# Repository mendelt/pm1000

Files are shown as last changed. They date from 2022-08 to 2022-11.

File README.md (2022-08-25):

# Documentation for racking up Yamaha PM1000 channel strips

Requirements;
- Two channel strips in one 2U 19inch rack enclosure
- Internal power supply that provides 44V to two strips
  - We're assuming 100mA nominal power draw per channel strip 200mA peak (for now)
  - 44V (or 48V if possible) switchable phantom power
  - Uses 1x 44V or 2x 22V transformer (VA rating tbd)
- Phantom power is supplied via two 6k8 resistors and not via the center tap of the input transformer
- We're using the original Tamura input and output transformers where possible.
- Power switch on the front panel
- Power led on the front panel
- Phantom power switchable per channel
- Phantom power led per channel
- TS unbalanced instrument input

This project will include
- Instructions on how to prepare the channel strips
- PSU PCB design
- Front panel designs

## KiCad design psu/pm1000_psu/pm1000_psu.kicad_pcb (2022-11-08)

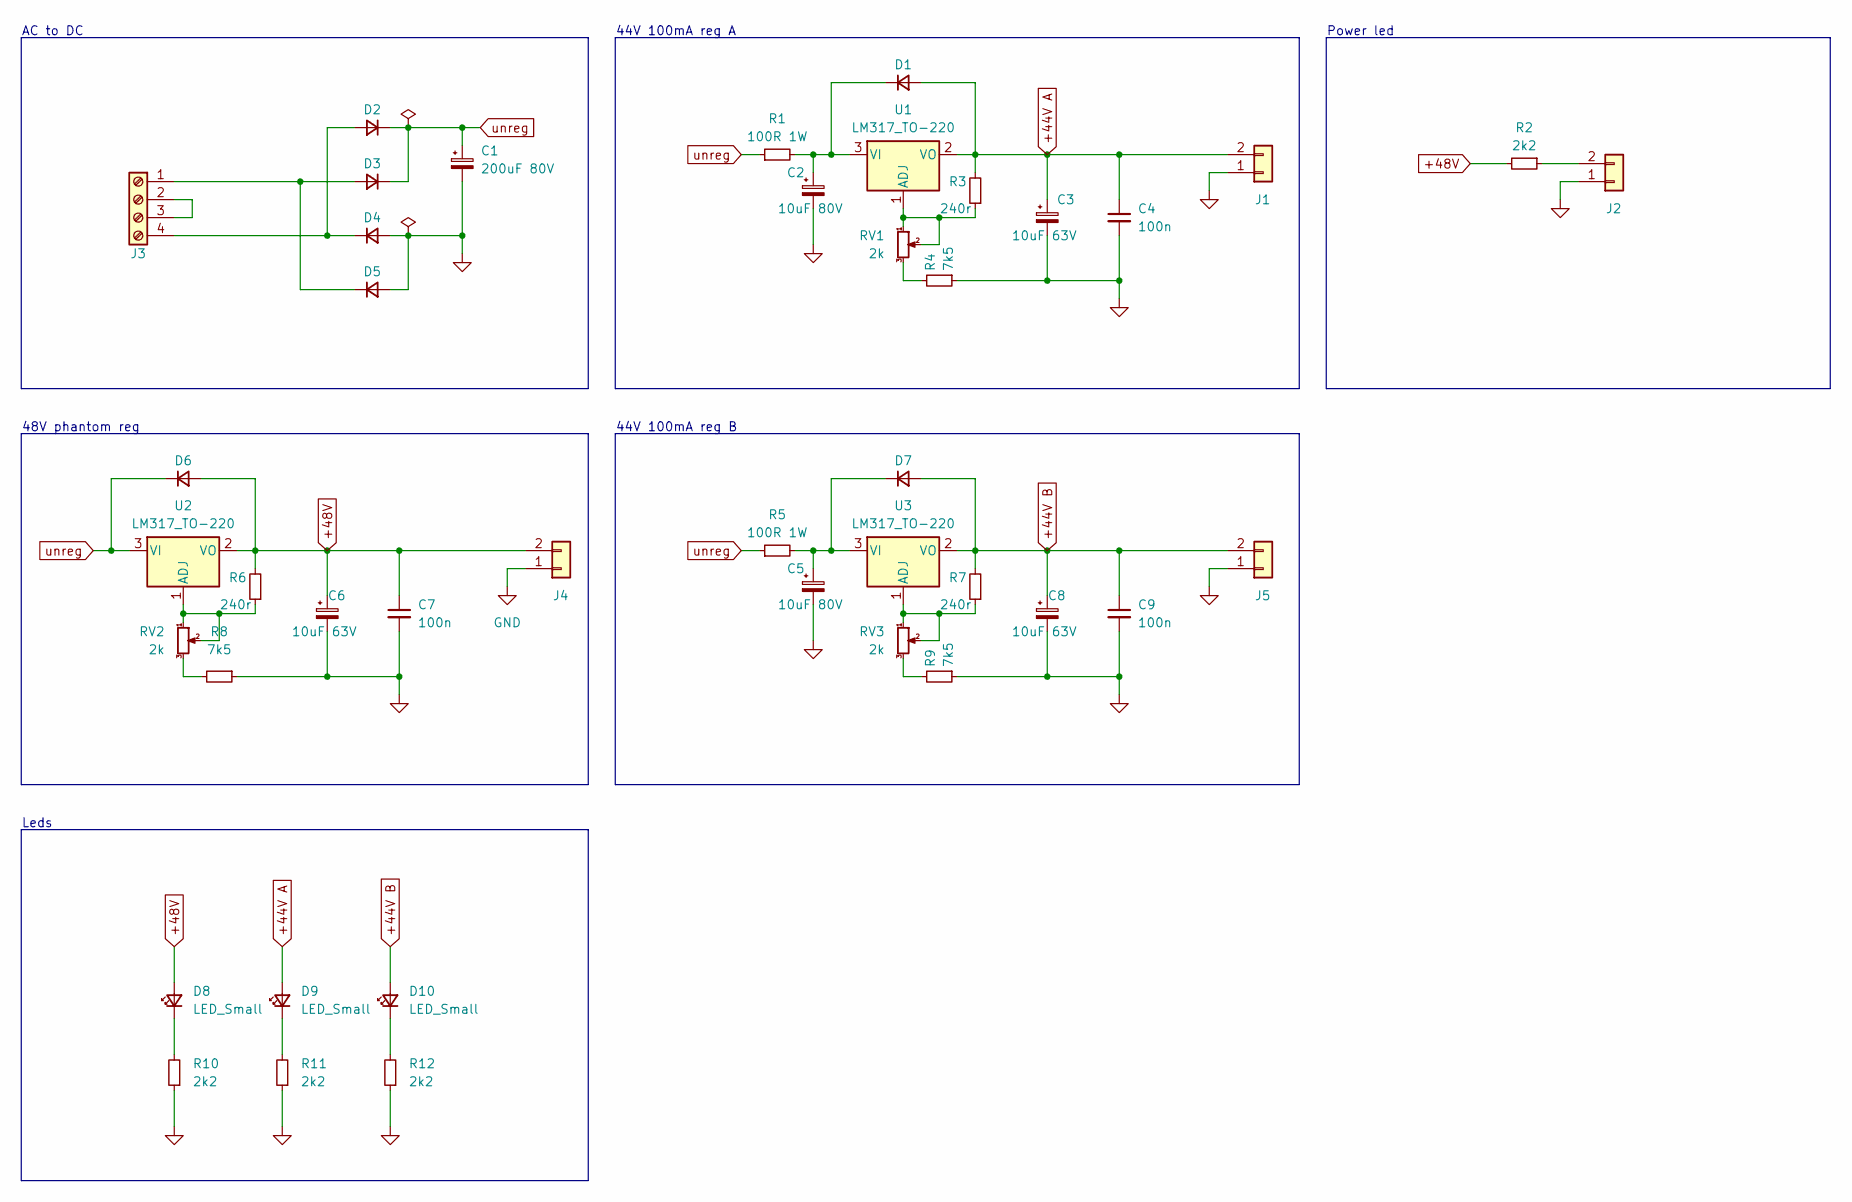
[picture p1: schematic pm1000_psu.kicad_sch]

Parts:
C1: 200uF 80V; CP_Radial_D12.5mm_P5.00mm
C2, C5: 10uF 80V; CP_Radial_D6.3mm_P2.50mm
C3, C6, C8: 10uF 63V; CP_Radial_D6.3mm_P2.50mm
C4, C7, C9: 100n; C_Disc_D5.0mm_W2.5mm_P2.50mm
D1, D2, D3, D4, D5, D6, D7: 1n4004; D_DO-41_SOD81_P10.16mm_Horizontal
D8, D9, D10: LED_Small; LED_D3.0mm
J1, J5: Molex_KK-396_5273-02A_1x02_P3.96mm_Vertical
J2, J4: Molex_KK-254_AE-6410-02A_1x02_P2.54mm_Vertical
J3: TerminalBlock_Phoenix_PT-1,5-4-5.0-H_1x04_P5.00mm_Horizontal
R1, R5: 100R 1W; R_Axial_DIN0411_L9.9mm_D3.6mm_P15.24mm_Horizontal; Mouser # 603-MFR100FTE52-1R
R2, R10, R11, R12: 2k2; R_Axial_DIN0207_L6.3mm_D2.5mm_P10.16mm_Horizontal; Mouser # 603-MFR-25FRF52-2K2
R3, R6, R7: 240r; R_Axial_DIN0207_L6.3mm_D2.5mm_P10.16mm_Horizontal; Mouser # 603-MFR-25FRF52-240R
R4, R8, R9: 7k5; R_Axial_DIN0207_L6.3mm_D2.5mm_P10.16mm_Horizontal; Mouser # 603-MFR-25FRF52-7K5
RV1, RV2, RV3: 2k; Potentiometer_Piher_PT-10-V05_Vertical
U1, U2, U3: LM317_TO-220; TO-220-3_Vertical; Mouser # 511-LM317BT

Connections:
+44V A: C3.1, C4.1, D1.2 (A), D9.2 (A), J1.2, R3.2, U1.2 (VO)
+44V B: C8.1, C9.1, D7.2 (A), D10.2 (A), J5.2, R7.2, U3.2 (VO)
+48V: C6.1, C7.1, D6.2 (A), D8.2 (A), J4.2, R2.2, R6.2, U2.2 (VO)
GND: C1.2, C2.2, C3.2, C4.2, C5.2, C6.2, C7.2, C8.2, C9.2, D4.2 (A), D5.2 (A), J1.1, J2.1, J4.1, J5.1, R4.1, R8.1, R9.1, R10.1, R11.1, R12.1
unnamed: C2.1, D1.1 (K), R1.2, U1.3 (VI)
unnamed: C5.1, D7.1 (K), R5.2, U3.3 (VI)
unnamed: D2.2 (A), D4.1 (K), J3.4
unnamed: D3.2 (A), D5.1 (K), J3.1
unnamed: D8.1 (K), R10.2
unnamed: D9.1 (K), R11.2
unnamed: D10.1 (K), R12.2
unnamed: J2.2, R2.1
unnamed: J3.2, J3.3
unnamed: R3.1, RV1.1, RV1.2, U1.1 (ADJ)
unnamed: R4.2, RV1.3
unnamed: R6.1, RV2.1, RV2.2, U2.1 (ADJ)
unnamed: R7.1, RV3.1, RV3.2, U3.1 (ADJ)
unnamed: R8.2, RV2.3
unnamed: R9.2, RV3.3
unreg: C1.1, D2.1 (K), D3.1 (K), D6.1 (K), R1.1, R5.1, U2.3 (VI)

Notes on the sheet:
44V 100mA reg A
Leds
44V 100mA reg B
Power led
48V phantom reg
AC to DC

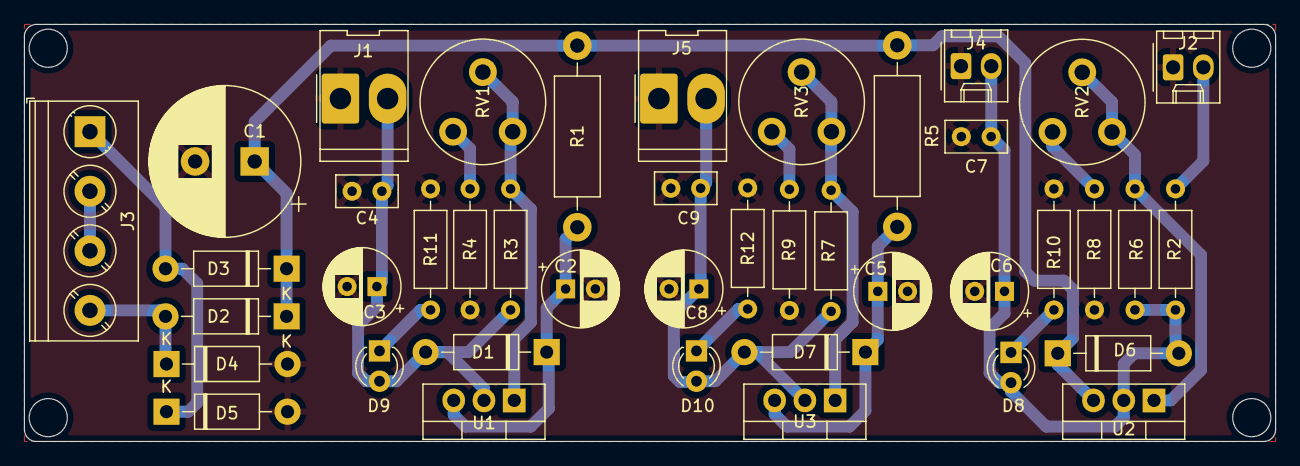
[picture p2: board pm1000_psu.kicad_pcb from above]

Board: 2 copper layers, 105.0 x 35.0 mm, 42 parts (0 on the bottom side), 20 nets.

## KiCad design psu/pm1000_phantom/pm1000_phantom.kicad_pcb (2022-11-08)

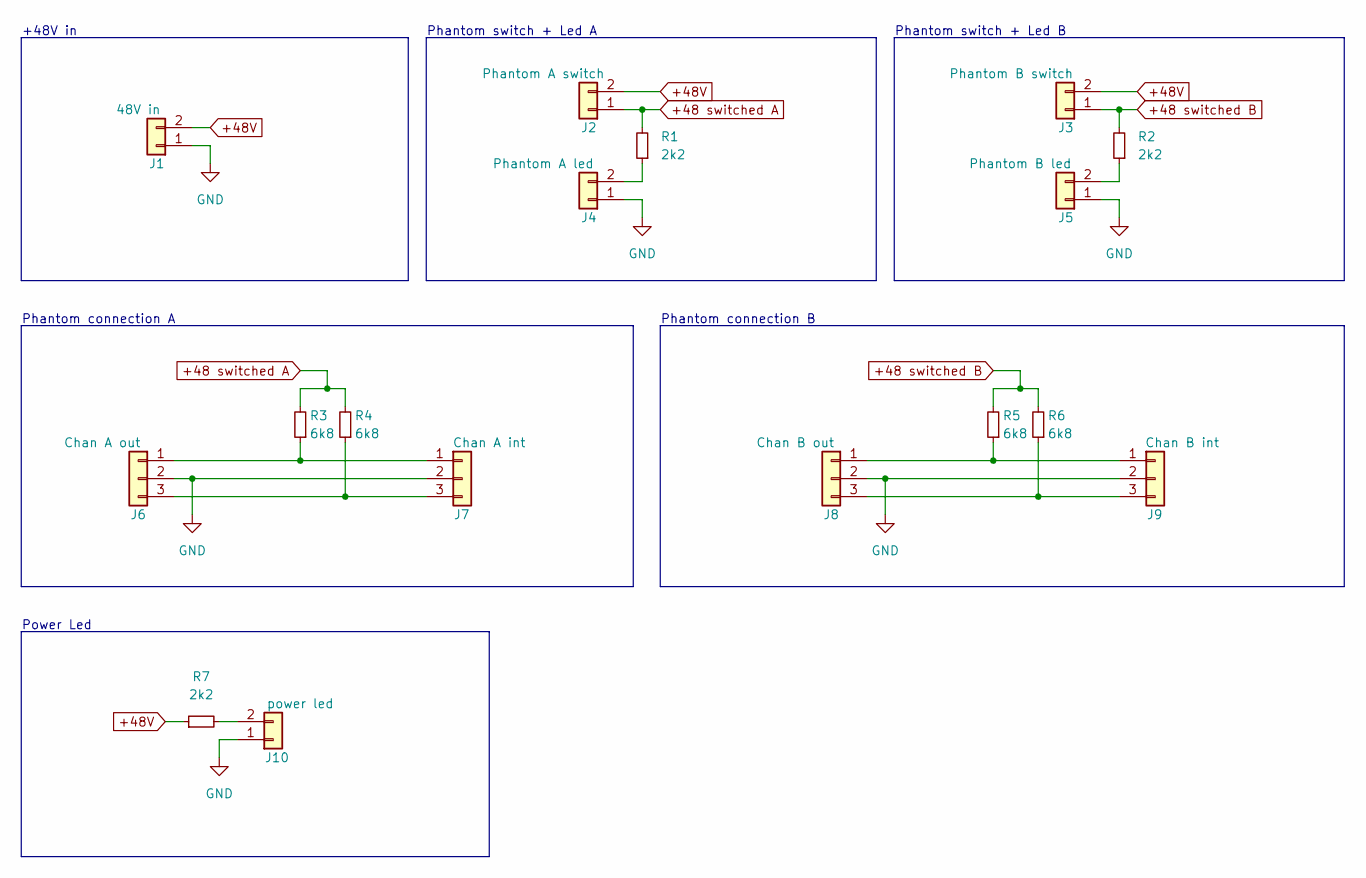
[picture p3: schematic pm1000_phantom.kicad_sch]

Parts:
J1, J2, J3, J4, J5, J10: 2 pin 2,54mm Molex; Molex_KK-254_AE-6410-02A_1x02_P2.54mm_Vertical; Mouser # 538-22-23-2028
J6, J7, J8, J9: 3 pin 2,54mm Molex; Molex_KK-254_AE-6410-03A_1x03_P2.54mm_Vertical; Mouser # 538-22-04-5032
R1, R2, R7: 2k2; R_Axial_DIN0207_L6.3mm_D2.5mm_P10.16mm_Horizontal; Mouser # 603-MFR-25FRF52-2K2
R3, R4, R5, R6: 6k8; R_Axial_DIN0207_L6.3mm_D2.5mm_P10.16mm_Horizontal; Mouser # 603-MFR-25FRF52-6K8

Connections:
+48 switched A: J2.1, R1.2, R3.2, R4.2
+48 switched B: J3.1, R2.2, R5.2, R6.2
+48V: J1.2, J2.2, J3.2, R7.1
GND: J1.1, J4.1, J5.1, J6.2, J7.2, J8.2, J9.2, J10.1
unnamed: J4.2, R1.1
unnamed: J5.2, R2.1
unnamed: J6.1, J7.1, R3.1
unnamed: J6.3, J7.3, R4.1
unnamed: J8.1, J9.1, R5.1
unnamed: J8.3, J9.3, R6.1
unnamed: J10.2, R7.2

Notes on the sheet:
+48V in
Phantom connection A
Power Led
Phantom connection B
Phantom switch + Led B
Phantom switch + Led A

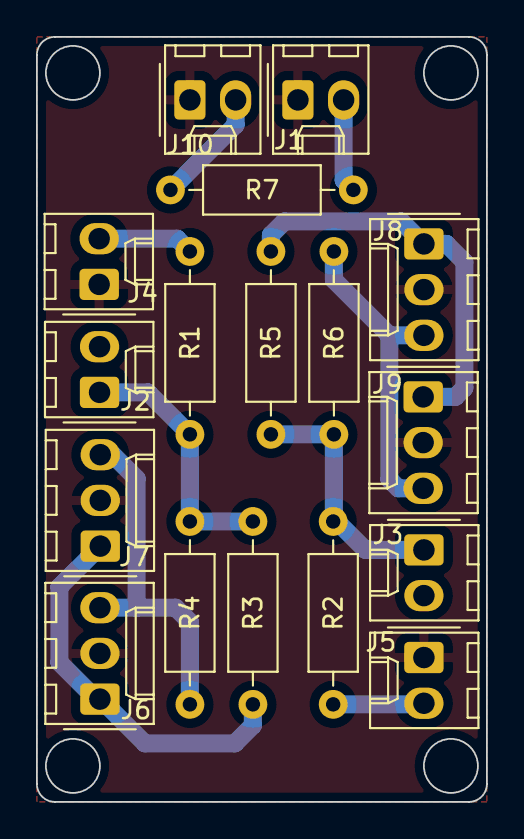
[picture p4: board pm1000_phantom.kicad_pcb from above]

Board: 2 copper layers, 25.0 x 42.5 mm, 17 parts (0 on the bottom side), 11 nets.

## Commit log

2022-08-26 add psu kicad project with first schematic outline
    [pm1000_psu.kicad_pcb, pm1000_psu.kicad_sch]
2022-08-27 clean up schematic
    [pm1000_psu.kicad_sch]
2022-08-27 update schematic
    - add diode footprints
    - add reg protection diodes
    - add trimmers
    - cleanup
    [pm1000_psu.kicad_sch]
2022-09-11 calculate values and add some footprints
    [pm1000_psu.kicad_sch]
2022-09-12 add rest of the footprints
    [pm1000_psu.kicad_sch]
2022-09-12 split psu and phantom pcb
    [pm1000_psu.kicad_pcb, pm1000_psu.kicad_sch]
2022-09-14 rename phantom board files and do some placement
    [pm1000_phantom.kicad_pcb, pm1000_phantom.kicad_sch, pm1000_psu.kicad_pcb]
2022-09-18 layout and route pcb board
    [pm1000_psu.kicad_pcb, pm1000_psu.kicad_sch]
2022-09-20 update phantom board
    [pm1000_phantom.kicad_pcb, pm1000_phantom.kicad_sch]
2022-09-25 update boms with (some) mouser part numbers add 100n capacitors add power leds add frontpanel power led connector to psu board
    [pm1000_phantom.kicad_pcb, pm1000_phantom.kicad_sch, pm1000_psu.kicad_pcb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]
2022-10-01 add power pins for cpu
    [pm1000_psu.kicad_sch]
2022-10-01 rework the psu layout a bit
    [pm1000_psu.kicad_pcb, pm1000_psu.kicad_sch]
2022-10-01 simplify filter stages for 44v channels
    [pm1000_psu.kicad_pcb, pm1000_psu.kicad_sch]
2022-10-17 increase pre reg filter r to 100ohm to accomodate for the lower current
    [pm1000_psu.kicad_sch]
2022-10-17 new layout
    [pm1000_psu.kicad_pcb, pm1000_psu.kicad_sch]
2022-10-19 route psu pcb
    [pm1000_psu.kicad_pcb, pm1000_psu.kicad_sch]
2022-10-19 phantom board: connect mic input gnd
    [pm1000_phantom.kicad_sch]
2022-10-19 route phantom pcb
    [pm1000_phantom.kicad_pcb]
2022-12-30 update component values and mouser numbers for easy ordering
    [pm1000_psu.kicad_sch]
2026-02-15 clean up projects and update to kicad 9
2026-02-15 psu schematic, add 5-terminal input with ground connection
2026-02-15 phantom: increase board size, better clearances
2026-02-15 set led resistors to 22k, place new psu terminal block
2026-02-15 clean up output board
2026-02-15 clean up project structure, organize psu silkscreen
2026-08-15 add output board dimensions
2026-10-18 fix phantom board labels
2026-10-18 re-engineer psu board
2026-10-18 add freecad files for 3d printed support brackets
2026-10-18 phantom board connector descriptions
